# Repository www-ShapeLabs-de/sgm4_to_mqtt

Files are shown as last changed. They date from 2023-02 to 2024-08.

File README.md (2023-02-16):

# ESP8266 electricity meter reading head for SGM-C4 meter with homeassistant mqtt-discovery
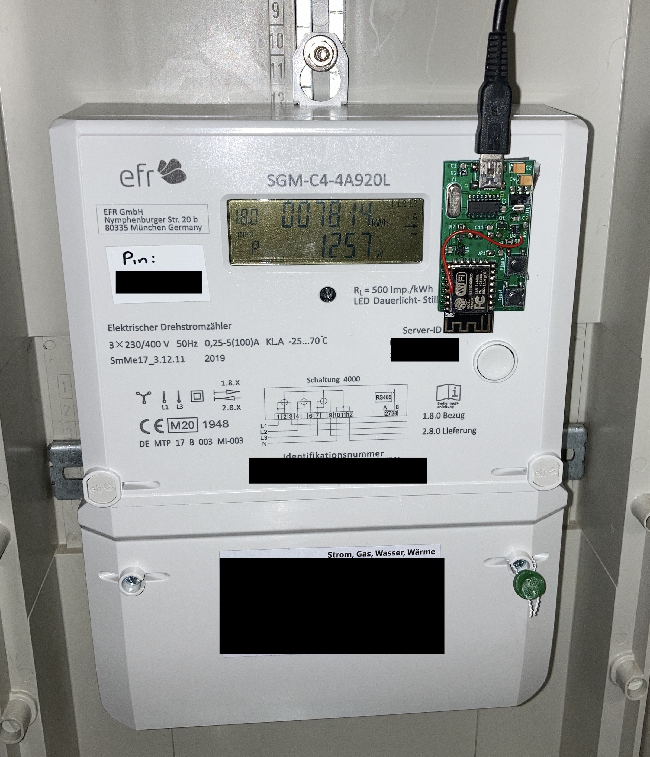
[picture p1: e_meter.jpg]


## Introduction
This project represents a complete electricity meter reading head for the SGM-C4 meter based on ESP8266. No other hardware like a Raspberry-Pi or similar is needed except for the hardware mentioned here. This read head is specially developed for homeassistant, but can also be used for other home automation systems via manual MQTT configuration.
The SML data set is read from the SGM-C4 meter via the optical interface and decoded. The data is transferred to homeassistant via MQTT. At startup, the read head automatically sets itself up as a device via mqtt-discovery with all its entities.

## Hardware
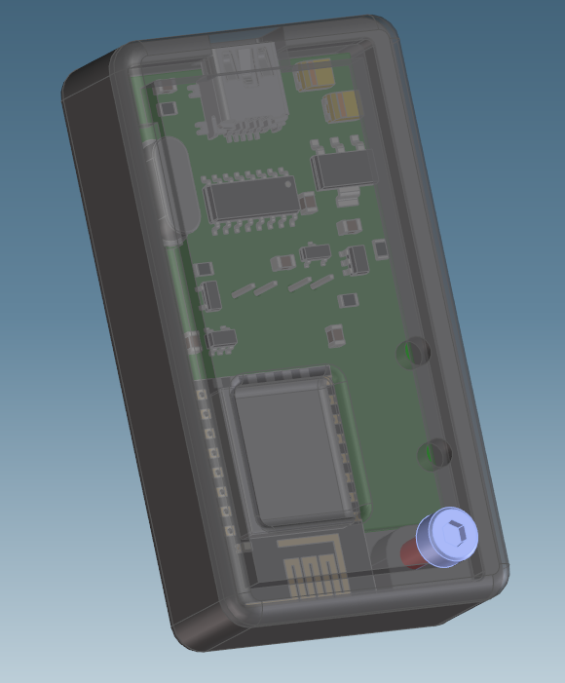
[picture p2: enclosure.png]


### Electronics
All components are easy to obtain, the optical TX side (U5, Q2, D1, R7, C10) can also remain unpopulated. Currently it is not used. When choosing the IR receiving diode (Q3) the SFH309 should be used. With other diodes there could be problems. Otherwise the circuit is quite trivial and should be easy to build and populate. Board data are available as KiCad files in the repo. For standard-use it's necessary to set Jumper JP2 to 1-2

### Housing
CAD data for a housing is available as a STEP file. There are also STL files that can be printed directly. If no printer is available, the circuit board can also be attached to the electricity meter with double-sided adhesive tape and a few plastic plates (approx. 3 mm thick) as a spacer block.

## Software / Config
For this project it is necessary to enable the complete data output of the electricity meter by means of a PIN code. You can get the PIN code from your metering point operator (in german: "Messstellenbetreiber"), a phone call is sufficient. The metering point operator is obliged to provide the PIN code. For this purpose, you should have the customer data and the meter number available.

### Entering the PIN code
To enter the PIN, you must first press the mechanical key once. After that, the PIN display appears in the lower display line and the first digit appears with a
"0". To enter your PIN, press the key repeatedly until the value of the first digit of your personal PIN appears in the display. After a short waiting time the device is ready (display of a "0") for the input of the 2nd digit of your PIN. Enter the corresponding value of your personal PIN here as well. Then repeat the entry procedure for the 3rd and 4th digits of your PIN in the same way. 

### Configuration of the software
The WLAN access data must be entered in the #define area of the software. In addition, the address or IP of the MQTT broker and its access data are required.
Under "Location" and "Name" the device name as well as its installation location can be assigned. This also results in the MQTT topic. 

```
#define SOFTWARE_VERSION      "v1.4"
#define WLAN_SSID             "myssid"
#define WLAN_PASS             "mywifipasswd"
#define MQTT_SERVER           "192.168.1.2"
#define MQTT_SERVERPORT       1883 					// use 8883 for SSL
#define MQTT_USERNAME         "mqttuser"
#define MQTT_KEY              "mosquitto"
#define LOCATION              "my_location"
#define NAME                  "E_Meter"
//#define OTA_PASS            "admin"
#define STATE_UPDATE_INTERVAL 5000 					// MQTT state update interval in [ms] (<5000ms could be critical for parsing in worst case)
#define AVAILABILITY_ONLINE   "online"
#define AVAILABILITY_OFFLINE  "offline"
```

Afterwards the software can be flashed to the ESP8266 with a mini-USB cable and the Arduino IDE. To enter the flash mode, the flash button must be held down while pressing the reset button. After the flash process, the ESP should be reset again.

After that the device should be found automatically in HASSIO with all its entities:

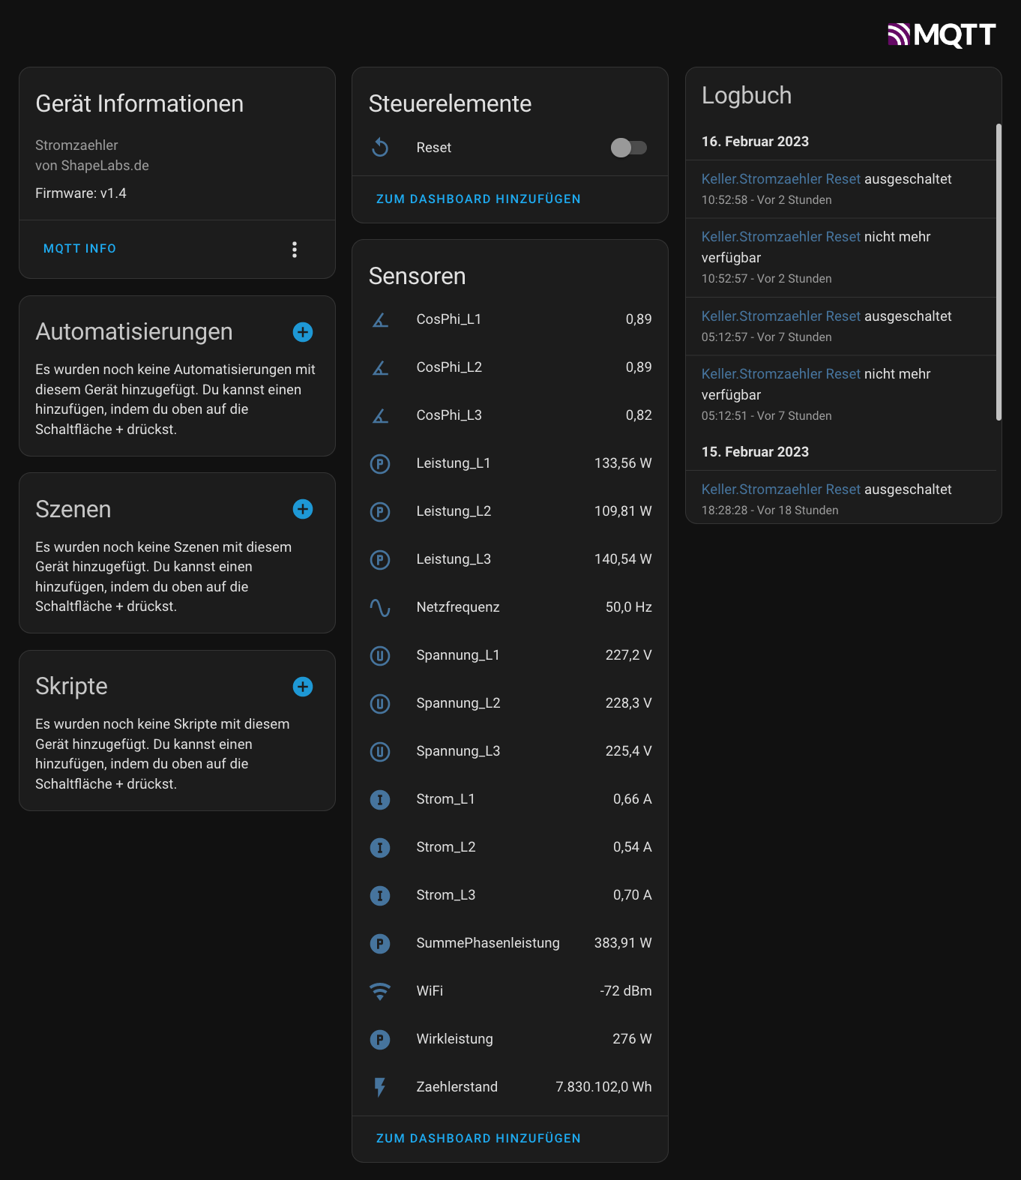
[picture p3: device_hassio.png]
The Device with its entities in HASSIO


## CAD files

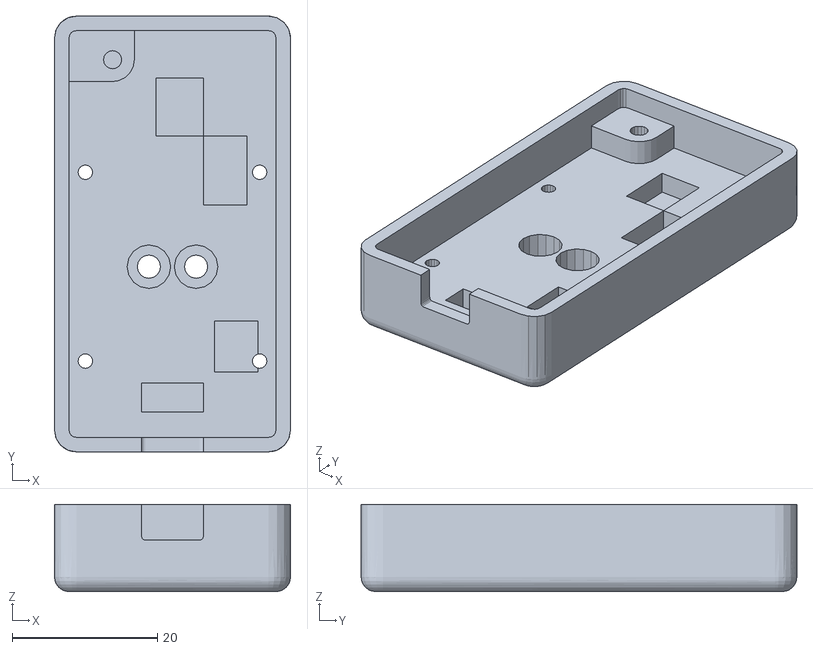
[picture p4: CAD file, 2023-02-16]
Enclosure/electricity_meter_reading_head_enclosure_bottom.stl
32.5 x 60.0 x 12.0

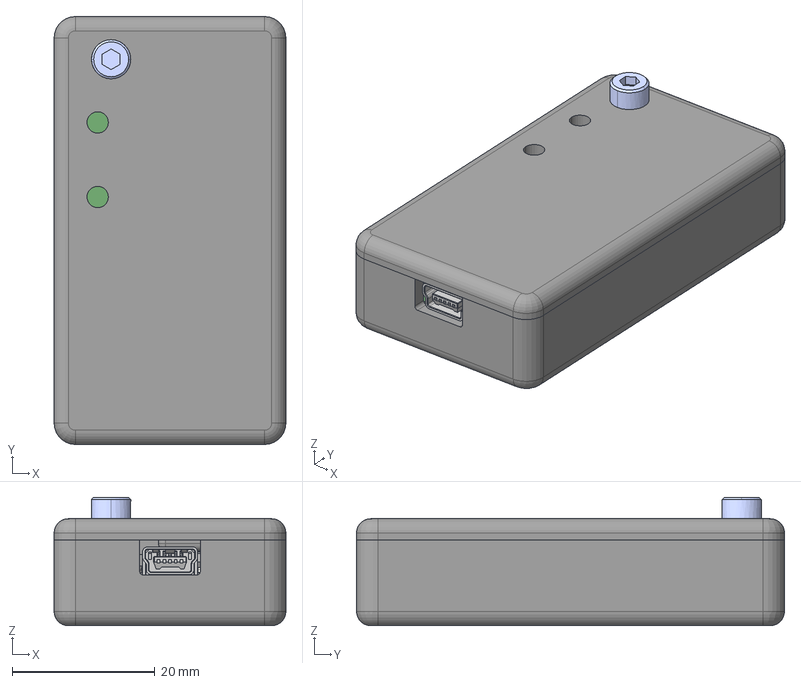
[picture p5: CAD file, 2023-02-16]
Enclosure/electricity_meter_reading_head_enclosure.stp
32.5 x 60.0 x 18.0 mm
Srew_M3x10_DIN912
USB_Mini_B_SMD_buchse
T48
T47
T46
T45
T44
T43
T42
T41
T40
T39
T38
T37
T36
T35
T34
T33
T32
T31
T30
T29
T28
T27
T26
T25
T24
T23
T22
T21
T20
T19
T18
T17
T16
T15
T14
T13
T12
T11
T10
T9
T8
T7
T6
T5
T4
T3
T2
T1
B1
Print_Enclosure_Top
Print_Enclosure_Bottom

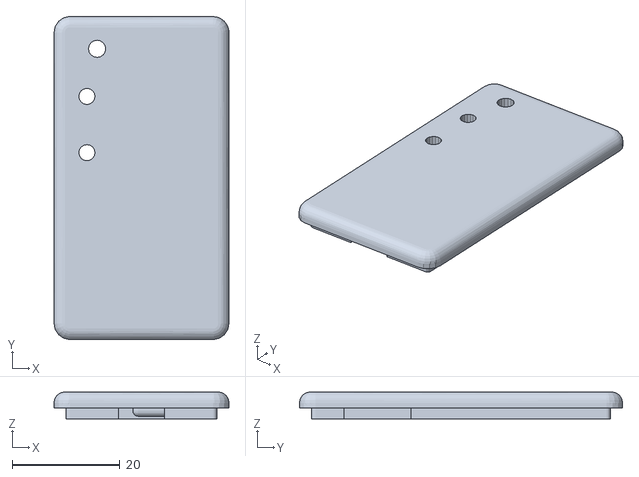
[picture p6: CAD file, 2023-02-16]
Enclosure/electricity_meter_reading_head_enclosure_top.stl
32.5 x 60.0 x 5.00

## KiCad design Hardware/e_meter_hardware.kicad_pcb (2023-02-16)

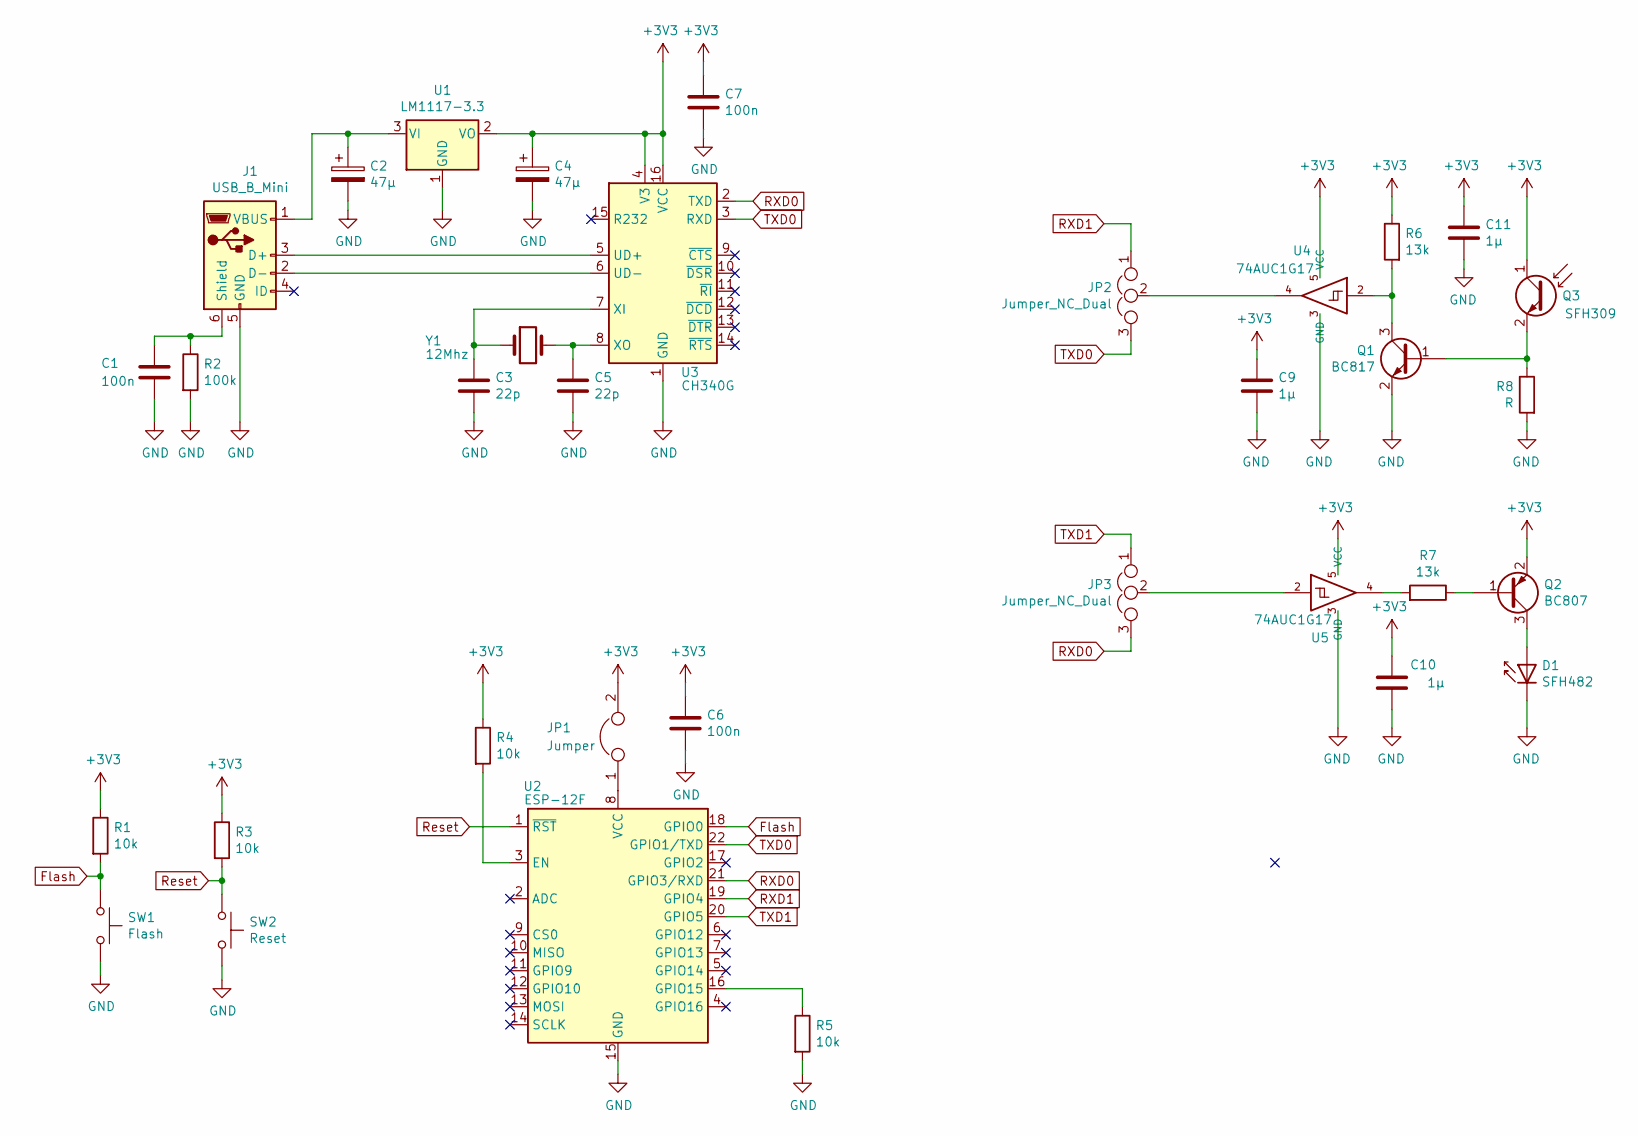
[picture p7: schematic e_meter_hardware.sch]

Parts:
C1, C6, C7: 100n; C_0805_2012Metric
C2, C4: 47µ; CP_EIA-3528-21_Kemet-B
C3, C5: 22p; C_0805_2012Metric
C9, C10, C11: 1µ; C_0805_2012Metric
D1: SFH482; LED_D3.0mm_Clear
J1: USB_B_Mini; USB_Mini-B_Wuerth_65100516121_Horizontal
JP1: Jumper; SolderJumper-2_P1.3mm_Open_RoundedPad1.0x1.5mm
JP2, JP3: Jumper_NC_Dual; SolderJumper-3_P1.3mm_Open_RoundedPad1.0x1.5mm
Q1: BC817; SOT-23
Q2: BC807; SOT-23
Q3: SFH309; LED_D3.0mm_Clear
R1, R3, R4, R5: 10k; R_0805_2012Metric
R2: 100k; R_0805_2012Metric
R6, R7: 13k; R_0805_2012Metric
R8: R; R_0805_2012Metric
SW1: Flash; SW_Push_1P1T_NO_6x6mm_H9.5mm
SW2: Reset; SW_Push_1P1T_NO_6x6mm_H9.5mm
U1: LM1117-3.3; SOT-223-3_TabPin2
U2: ESP-12F; ESP-12E
U3: CH340G; SOIC-16_3.9x9.9mm_P1.27mm
U4, U5: 74AUC1G17; SOT-23-5
Y1: 12Mhz; Crystal_HC49-U_Vertical

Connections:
+3V3: C4.1, C6.1, C7.1, C9.1, C10.1, C11.1, JP1.2, Q2.2 (E), Q3.1 (C), R1.1, R3.1, R4.1, R6.1, U1.2 (VO), U3.4 (V3), U3.16 (VCC), U4.5 (VCC), U5.5 (VCC)
Flash: R1.2, SW1.1, U2.18 (GPIO0)
GND: C1.2, C2.2, C3.2, C4.2, C5.2, C6.2, C7.2, C9.2, C10.2, C11.2, D1.1 (K), J1.5 (GND), Q1.2 (E), R2.2, R5.2, R8.2, SW1.2, SW2.2, U1.1 (GND), U2.15 (GND), U3.1 (GND), U4.3 (GND), U5.3 (GND)
unnamed: C1.1, J1.6 (Shield), R2.1
unnamed: C2.1, J1.1 (VBUS), U1.3 (VI)
unnamed: C3.1, U3.7 (XI), Y1.1
unnamed: C5.1, U3.8 (XO), Y1.2
unnamed: D1.2 (A), Q2.3 (C)
unnamed: J1.2 (D-), U3.6 (UD-)
unnamed: J1.3 (D+), U3.5 (UD+)
unnamed: JP1.1, U2.8 (VCC)
unnamed: JP2.2, U4.4
unnamed: JP3.2, U5.2
unnamed: Q1.1 (B), Q3.2 (E), R8.1
unnamed: Q1.3 (C), R6.2, U4.2
unnamed: Q2.1 (B), R7.1
unnamed: R4.2, U2.3 (EN)
unnamed: R5.1, U2.16 (GPIO15)
unnamed: R7.2, U5.4
RXD0: JP3.3, U2.21 (GPIO3/RXD), U3.2 (TXD)
RXD1: JP2.1, U2.19 (GPIO4)
Reset: R3.2, SW2.1, U2.1 (~RST)
TXD0: JP2.3, U2.22 (GPIO1/TXD), U3.3 (RXD)
TXD1: JP3.1, U2.20 (GPIO5)

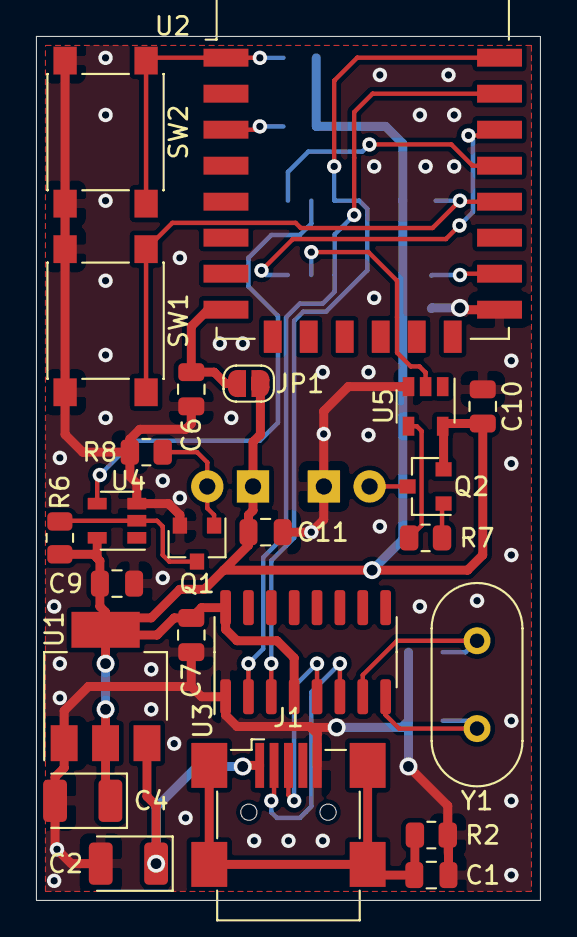
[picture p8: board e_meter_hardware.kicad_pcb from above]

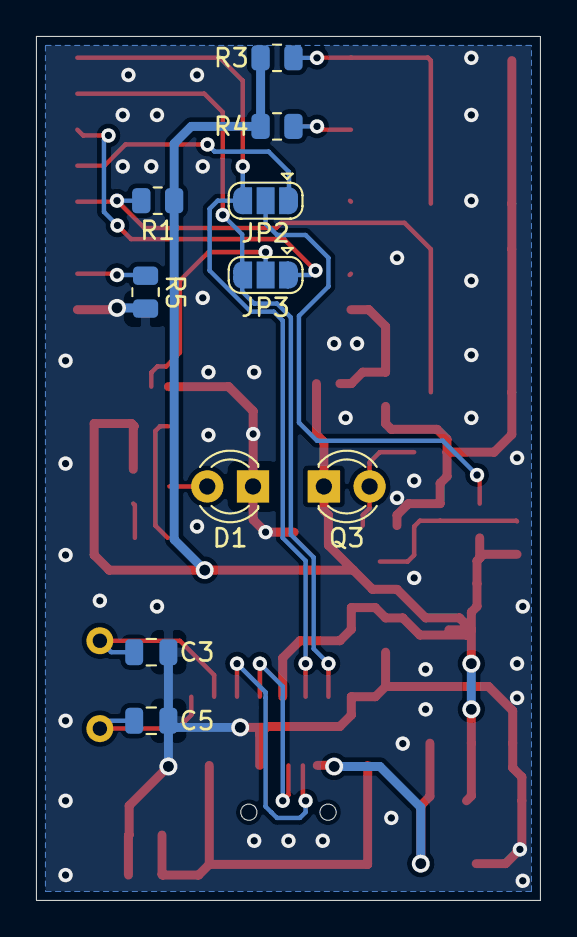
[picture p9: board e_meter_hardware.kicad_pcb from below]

Board: 2 copper layers, 28.0 x 48.0 mm, 34 parts (10 on the bottom side), 24 nets.

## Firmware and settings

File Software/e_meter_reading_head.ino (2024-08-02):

/*------------------------------------------------------------------------------
 Copyright:	  Henning Schaper  mailto: henningschaper@gmx.de
 Author:		 Henning Schaper
 Remarks:		none
 known Problems: none
 Version:		v1.4	01.04.2022
 Description:  	 Hassio 
 				 Processor: ESP8266 (ESP12F)
 				 Features:  - homeassistant autoconfig
 				 			- OTA
 				 			- JSON over MQTT 
 				 			- 
 				 			- 
 				 			- static wifi, no wifimanager (more stable)

------------------------------------------------------------------------------*/

//----------------------------------------------------------------------------//
//-------------------------------- Includes  ---------------------------------//
//----------------------------------------------------------------------------//
#include <ESP8266WiFi.h>
#include <ArduinoJson.h>
#include <PubSubClient.h>
#include <ArduinoOTA.h>
#include <SoftwareSerial.h>

//----------------------------------------------------------------------------//
//-------------------------------- Config  -----------------------------------//
//----------------------------------------------------------------------------//
#define SOFTWARE_VERSION		"v1.6"
#define WLAN_SSID 				"myssid"
#define WLAN_PASS 				"mypass"
#define MQTT_SERVER 			"192.168.2.5"
#define MQTT_SERVERPORT 		1883 					// use 8883 for SSL
#define MQTT_USERNAME 			"mqttuser"
#define MQTT_KEY 				"mosquitto"
#define LOCATION				"Keller"
#define NAME 					"Stromzaehler"
//#define OTA_PASS				"admin"
#define STATE_UPDATE_INTERVAL	5000 					// MQTT state update interval in [ms] (<5000ms could be critical for parsing in worst case)
#define AVAILABILITY_ONLINE 	"online"
#define AVAILABILITY_OFFLINE 	"offline"
#define DEBUG
//#define DEBUG2

//----------------------------------------------------------------------------//
//--------------------------------- Macros -----------------------------------//
//----------------------------------------------------------------------------//
#define SOFT_RX_PIN		4
#define SOFT_TX_PIN		5
#define SML_MESSAGE_SIZE 600

//----------------------------------------------------------------------------//
//----------------------------- Constants & LUTs -----------------------------//
//----------------------------------------------------------------------------//
const uint8_t startSequence[] = 						{ 0x1B, 0x1B, 0x1B, 0x1B, 0x01, 0x01, 0x01, 0x01 }; //start sequence of SML protocol
const uint8_t stopSequence[]  = 						{ 0x1B, 0x1B, 0x1B, 0x1B, 0x1A }; //end sequence of SML protocol

const uint8_t Zaehlerstand_Bezug_sequence[] = 			{0x77, 0x07, 0x01, 0x00, 0x01, 0x08, 0x00, 0xFF}; 
const uint8_t Zaehlerstand_Einspeisung_sequence[] = 	{0x77, 0x07, 0x01, 0x00, 0x02, 0x08, 0x00, 0xFF}; 
const uint8_t Wirkleistung_sequence[] = 				{0x77, 0x07, 0x01, 0x00, 0x10, 0x07, 0x00, 0xFF}; 
const uint8_t Spannung_L1_sequence[] = 					{0x77, 0x07, 0x01, 0x00, 0x20, 0x07, 0x00, 0xFF}; 
const uint8_t Spannung_L2_sequence[] = 					{0x77, 0x07, 0x01, 0x00, 0x34, 0x07, 0x00, 0xFF}; 
const uint8_t Spannung_L3_sequence[] = 					{0x77, 0x07, 0x01, 0x00, 0x48, 0x07, 0x00, 0xFF}; 
const uint8_t Strom_L1_sequence[] = 					{0x77, 0x07, 0x01, 0x00, 0x1F, 0x07, 0x00, 0xFF}; 
const uint8_t Strom_L2_sequence[] = 					{0x77, 0x07, 0x01, 0x00, 0x33, 0x07, 0x00, 0xFF}; 
const uint8_t Strom_L3_sequence[] = 					{0x77, 0x07, 0x01, 0x00, 0x47, 0x07, 0x00, 0xFF}; 
//const uint8_t Phasenwinkel_U-L2_U-L1_sequence[] = 		{0x77, 0x07, 0x01, 0x00, 0x51, 0x07, 0x01, 0xFF}; 
//const uint8_t Phasenwinkel_U-L3_U-L1_sequence[] = 		{0x77, 0x07, 0x01, 0x00, 0x51, 0x07, 0x02, 0xFF}; 
const uint8_t Phi_L1_sequence[] = 						{0x77, 0x07, 0x01, 0x00, 0x51, 0x07, 0x04, 0xFF}; 
const uint8_t Phi_L2_sequence[] = 						{0x77, 0x07, 0x01, 0x00, 0x51, 0x07, 0x0F, 0xFF}; 
const uint8_t Phi_L3_sequence[] = 						{0x77, 0x07, 0x01, 0x00, 0x51, 0x07, 0x1A, 0xFF}; 
const uint8_t Frequenz_sequence[] = 					{0x77, 0x07, 0x01, 0x00, 0x0E, 0x07, 0x00, 0xFF}; 

const float cos_table [] = 	{	1.000000, 0.999847, 0.999389, 0.998626, 0.997557, 0.996184, 0.994507, 0.992526, 0.990241, 0.987655,
 								0.984766, 0.981577, 0.978088, 0.974300, 0.970215, 0.965833, 0.961156, 0.956186, 0.950923, 0.945370, 
 								0.939529, 0.933400, 0.926987, 0.920290, 0.913312, 0.906055, 0.898521, 0.890713, 0.882633, 0.874283, 
 								0.865666, 0.856785, 0.847642, 0.838240, 0.828582, 0.818671, 0.808510, 0.798102, 0.787451, 0.776558, 
 								0.765429, 0.754066, 0.742472, 0.730652, 0.718608, 0.706345, 0.693866, 0.681175, 0.668277, 0.655174, 
 								0.641871, 0.628371, 0.614680, 0.600802, 0.586739, 0.572498, 0.558081, 0.543495, 0.528742, 0.513827, 
 								0.498756, 0.483532, 0.468161, 0.452647, 0.436994, 0.421208, 0.405293, 0.389255, 0.373097, 0.356826, 
 								0.340446, 0.323961, 0.307378, 0.290701, 0.273935, 0.257085, 0.240157, 0.223155, 0.206086, 0.188953, 
 								0.171763, 0.154520, 0.137230, 0.119898, 0.102529, 0.085129, 0.067703, 0.050257, 0.032795, 0.015323, 0.000000};

//----------------------------------------------------------------------------//
//------------------------------- Variables  ---------------------------------//
//----------------------------------------------------------------------------//
uint8_t smlMessage[SML_MESSAGE_SIZE];
uint16_t parse_index = 0;
uint16_t smlIndex = 0;
uint8_t inByte = 0;
uint8_t startIndex = 0;
uint8_t stopIndex = 0;
uint8_t sml_read_state = 0;

double Zaehlerstand_180 = 0;
double Zaehlerstand_280 = 0;
double Wirkleistung = 0;
double SpannungL1 = 0;
double SpannungL2 = 0;
double SpannungL3 = 0;
double StromL1 = 0;
double StromL2= 0;
double StromL3= 0;
double Phi_L1 = 0;
double Phi_L2 = 0;
double Phi_L3 = 0;
double Netzfrequenz = 0;

char identifier[24];
char MQTT_TOPIC_AVAILABILITY[128];
char MQTT_TOPIC_STATE[128];
char MQTT_TOPIC_COMMAND[128];

uint32_t PreviousStateUpdateTime = 0;
uint32_t CurrentTime = millis();
bool parse_error_flag = false;

//----------------------------------------------------------------------------//
//--------------------------------- Objects ----------------------------------//
//----------------------------------------------------------------------------//
SoftwareSerial SoftSerial(SOFT_RX_PIN, SOFT_TX_PIN);
WiFiClient wifiClient;
PubSubClient mqttClient(wifiClient);

//----------------------------------------------------------------------------//
//------------------------------ Main Program --------------------------------//
//----------------------------------------------------------------------------//
void setup()
{
	Serial.begin(115200);
	Serial.println("Start INIT");
	SoftSerial.begin(9600);
	
	snprintf(identifier, sizeof(identifier), "%s.%s",LOCATION,NAME); 
	snprintf(MQTT_TOPIC_AVAILABILITY, 127, "%s/%s/status", LOCATION, NAME);
	snprintf(MQTT_TOPIC_STATE, 127, "%s/%s/state", LOCATION, NAME);
	snprintf(MQTT_TOPIC_COMMAND, 127, "%s/%s/command", LOCATION, NAME);

	connect_WiFi();
	setupOTA();
	
	mqttClient.setServer(MQTT_SERVER, MQTT_SERVERPORT);
	mqttClient.setKeepAlive(10);
	mqttClient.setBufferSize(2048);
	mqttClient.setCallback(mqttCallback);

	mqttReconnect();
	Serial.println("INIT COMPLETE!");
}

void loop()
{
	mqttClient.loop();
	ArduinoOTA.handle();

	if(!sml_read_state)
		get_sml_sync();
	else if (sml_read_state == 1)
		get_sml_message();
	else if(sml_read_state == 2)
	{
		Zaehlerstand_180 = get_values_from_SML(Zaehlerstand_Bezug_sequence);
		Zaehlerstand_280 = get_values_from_SML(Zaehlerstand_Einspeisung_sequence);
		Wirkleistung = get_values_from_SML(Wirkleistung_sequence);
		SpannungL1 = get_values_from_SML(Spannung_L1_sequence);
		SpannungL2 = get_values_from_SML(Spannung_L2_sequence);
		SpannungL3 = get_values_from_SML(Spannung_L3_sequence);
		StromL1 = get_values_from_SML(Strom_L1_sequence);
		StromL2 = get_values_from_SML(Strom_L2_sequence);
		StromL3 = get_values_from_SML(Strom_L3_sequence);
		Phi_L1 = get_values_from_SML(Phi_L1_sequence);
		Phi_L2 = get_values_from_SML(Phi_L2_sequence);
		Phi_L3 = get_values_from_SML(Phi_L3_sequence);
		Netzfrequenz = get_values_from_SML(Frequenz_sequence);

		if(!parse_error_flag)							//Parsing successfull completed?
			sml_read_state = 3;							//
		else											//else: Error@Parsing! Discard any data, to prevent publishing zero-values ore other wrong values
			sml_read_state = 0;							//go to next state of statemachine -> STATE 3: publishing data
	}
	
	if(STATE_UPDATE_INTERVAL <= (CurrentTime - PreviousStateUpdateTime))
	{
		if (WiFi.status() != WL_CONNECTED) 
			connect_WiFi(); 

		if (!mqttClient.connected())
			mqttReconnect();
		
		if(sml_read_state == 3)
		{
			#ifdef DEBUG
				Serial.println("Publish");
			#endif
			publishState();
			sml_read_state = 0;
		}
	}
	CurrentTime = millis();							// Get current time
}

//----------------------------------------------------------------------------//
//----------------------- Standard Functions for ESP -------------------------//
//----------------------------------------------------------------------------//
void Reset_ESP()
{
	WiFi.disconnect(true);
	delay(1000);
	ESP.restart();	
}

void connect_WiFi()
{
	Serial.print("Connecting to ");
	Serial.println(WLAN_SSID);
	
	WiFi.mode(WIFI_STA);
	WiFi.begin(WLAN_SSID, WLAN_PASS);

	while (WiFi.status() != WL_CONNECTED)
	{
		delay(100);
		Serial.print(".");
	}

	Serial.println("");
	Serial.println("WiFi connected");
	Serial.println("IP address: ");
	Serial.println(WiFi.localIP());
}

void setupOTA()
{
	ArduinoOTA.onStart([]() { Serial.println("Start"); });
	ArduinoOTA.onEnd([]() { Serial.println("\nEnd"); });

	ArduinoOTA.onProgress([](unsigned int progress, unsigned int total)
	{
		Serial.printf("Progress: %u%%\r\n", (progress / (total / 100)));
	});

	ArduinoOTA.onError([](ota_error_t error)
	{
		Serial.printf("Error[%u]: ", error);
		if (error == OTA_AUTH_ERROR) Serial.println("Auth Failed");
		else if (error == OTA_BEGIN_ERROR) Serial.println("Begin Failed");
		else if (error == OTA_CONNECT_ERROR) Serial.println("Connect Failed");
		else if (error == OTA_RECEIVE_ERROR) Serial.println("Receive Failed");
		else if (error == OTA_END_ERROR) Serial.println("End Failed");
	});

	ArduinoOTA.setHostname(identifier);
	#ifdef OTA_PASS
		ArduinoOTA.setPassword(OTA_PASS);
	#endif
	ArduinoOTA.begin();
}


void mqttReconnect()
{
	for(int attempt = 0; attempt < 3; ++attempt) 
	{
		Serial.print("Connecting MQTT....");
		if(mqttClient.connect(identifier, MQTT_USERNAME, MQTT_KEY, AVAILABILITY_ONLINE, 1, true, AVAILABILITY_OFFLINE)) 
		{	
			Serial.println("Connected!");
			mqttClient.publish(MQTT_TOPIC_AVAILABILITY, AVAILABILITY_ONLINE, true);
			
			Serial.println("Sending Autoconfig....");

			publish_autoconfig_entity("WiFi","dBm","mdi:wifi",3);
			publish_autoconfig_entity("Zaehlerstand_180","Wh","mdi:flash",1);
			publish_autoconfig_entity("Zaehlerstand_280","Wh","mdi:flash",1);
			publish_autoconfig_entity("Wirkleistung","W","mdi:alpha-p-circle",3);
			publish_autoconfig_entity("SummePhasenleistung","W","mdi:alpha-p-circle",3);
			publish_autoconfig_entity("Spannung_L1","V","mdi:alpha-u-circle-outline",3);
			publish_autoconfig_entity("Spannung_L2","V","mdi:alpha-u-circle-outline",3);
			publish_autoconfig_entity("Spannung_L3","V","mdi:alpha-u-circle-outline",3);
			publish_autoconfig_entity("Strom_L1","A","mdi:alpha-i-circle",3);
			publish_autoconfig_entity("Strom_L2","A","mdi:alpha-i-circle",3);
			publish_autoconfig_entity("Strom_L3","A","mdi:alpha-i-circle",3);
			publish_autoconfig_entity("cosPhi_L1"," ","mdi:angle-acute",3);
			publish_autoconfig_entity("cosPhi_L2"," ","mdi:angle-acute",3);
			publish_autoconfig_entity("cosPhi_L3"," ","mdi:angle-acute",3);
			publish_autoconfig_entity("Leistung_L1","W","mdi:alpha-p-circle-outline",3);
			publish_autoconfig_entity("Leistung_L2","W","mdi:alpha-p-circle-outline",3);
			publish_autoconfig_entity("Leistung_L3","W","mdi:alpha-p-circle-outline",3);
			publish_autoconfig_entity("Netzfrequenz","Hz","mdi:sine-wave",3);
			publish_autoconfig_entity("Reset"," ","mdi:replay" ,2);

			Serial.println("Subscribing Topics....");
			mqttClient.subscribe(MQTT_TOPIC_COMMAND);
			Serial.println("Success!");
			break;
		}
		else
		{
			delay(5000);
			Serial.print("FAILED, Retry...");
		}
	}
}

//----------------------------------------------------------------------------//
//----------------------------- MQTT Functions -------------------------------//
//----------------------------------------------------------------------------//
void mqttCallback(char* topic, byte* payload, unsigned int length)
{
	if (strcmp(topic, MQTT_TOPIC_COMMAND) == 0)
	{
		DynamicJsonDocument commandJson(256);
		char payloadText[length + 1];
		snprintf(payloadText, length + 1, "%s", payload);
		DeserializationError err = deserializeJson(commandJson, payloadText);

		if (!err)
		{
			String reset = commandJson["Reset"].as<String>();
			if (reset == "on")
				Reset_ESP();									//ECHO
		}
	}
}

void publishState()
{
	DynamicJsonDocument stateJson(512);
	char payload[512];
	
	float P_L1 = my_cos_phi(Phi_L1)*SpannungL1*StromL1;
	float P_L2 = my_cos_phi(Phi_L1)*SpannungL2*StromL2;
	float P_L3 = my_cos_phi(Phi_L1)*SpannungL3*StromL3;

	stateJson["Reset"] = "off";
	stateJson["WiFi"] = WiFi.RSSI();
	stateJson["Zaehlerstand_180"] = String(Zaehlerstand_180,1);
	stateJson["Zaehlerstand_280"] = String(Zaehlerstand_280,1);
	stateJson["Wirkleistung"] = String(Wirkleistung,0);
	stateJson["Spannung_L1"] = String(SpannungL1,1);
	stateJson["Spannung_L2"] = String(SpannungL2,1);
	stateJson["Spannung_L3"] = String(SpannungL3,1);
	stateJson["Strom_L1"] = String(StromL1,2);
	stateJson["Strom_L2"] = String(StromL2,2);
	stateJson["Strom_L3"] = String(StromL3,2);
	stateJson["cosPhi_L1"] = String(my_cos_phi(Phi_L1),2);
	stateJson["cosPhi_L2"] = String(my_cos_phi(Phi_L2),2);
	stateJson["cosPhi_L3"] = String(my_cos_phi(Phi_L3),2);
	stateJson["Leistung_L1"] = String(P_L1,2);
	stateJson["Leistung_L2"] = String(P_L2,2);
	stateJson["Leistung_L3"] = String(P_L3,2);
	stateJson["SummePhasenleistung"] = String(P_L1+P_L2+P_L3);
	stateJson["Netzfrequenz"] = String(Netzfrequenz,1);

	serializeJson(stateJson, payload);
	mqttClient.publish(MQTT_TOPIC_STATE, payload, true);

	PreviousStateUpdateTime = millis();
}

//TYPE: 1=Energy-Meter, 2=Switch, 3=Sensor
void publish_autoconfig_entity(const char value_name[], const char unit[], const char icon[], uint8_t type)
{
	char mqttPayload[1024];
	DynamicJsonDocument autoconfPayload(1024);
	DynamicJsonDocument device(256);
	char MQTT_TOPIC_AUTOCONF_TOPIC[128];

	device["identifiers"] = String("[") + identifier + String("]");
	device["manufacturer"] = "ShapeLabs.de";
	device["model"] = NAME;
	device["name"] = identifier;
	device["sw_version"] = SOFTWARE_VERSION;
	autoconfPayload["device"] = device.as<JsonObject>();
	autoconfPayload["availability_topic"] = MQTT_TOPIC_AVAILABILITY;
	autoconfPayload["state_topic"] = MQTT_TOPIC_STATE;
	autoconfPayload["name"] = identifier + String(" ") + value_name;
	autoconfPayload["unique_id"] = identifier + String("_") + value_name;
	autoconfPayload["icon"] = icon;
	autoconfPayload["value_template"] = String("{{value_json.") + value_name + String("}}");
	
	if(type==1)
	{
		autoconfPayload["device_class"] = "energy";
		autoconfPayload["state_class"] = "total_increasing";
		type = 3;
	}
	else if(type==2)
	{
		autoconfPayload["command_topic"] = MQTT_TOPIC_COMMAND;
		autoconfPayload["payload_on"] = String("{\"") + value_name + String("\": \"on\"}");
		autoconfPayload["payload_off"] = String("{\"") + value_name + String("\": \"off\"}");
		autoconfPayload["state_on"] = "on";
		autoconfPayload["state_off"] = "off";
		snprintf(MQTT_TOPIC_AUTOCONF_TOPIC, 127, "homeassistant/switch/%s/%s_%s/config", LOCATION, NAME, value_name);
	}
	if(type == 3)
	{
		autoconfPayload["unit_of_measurement"] = unit;
		snprintf(MQTT_TOPIC_AUTOCONF_TOPIC, 127, "homeassistant/sensor/%s/%s_%s/config", LOCATION, NAME, value_name);
	}

	serializeJson(autoconfPayload, mqttPayload);
	mqttClient.publish(MQTT_TOPIC_AUTOCONF_TOPIC, mqttPayload, true);
	device.clear();
	autoconfPayload.clear();
	delay(100);
}

//----------------------------------------------------------------------------//
//----------------------------- SML Functions --------------------------------//
//----------------------------------------------------------------------------//
void get_sml_sync()																//STATE 0: Function to finde the start sequence of an incomming sml-packet
{
	clear_all_sml();															//clear RX-Buffer, clear message buffer from any old data fragments, reset all flags and counter
	delay(20);																	//wait until there's any fresh data in the RX-buffer again

	while(SoftSerial.available())												//start to read the RX-buffer while there is any data
	{
		inByte = SoftSerial.read(); 											//reading data
		
		if(inByte == startSequence[startIndex]) 								//in case incomming byte matches the start sequence at position 0,1,2...
		{
			smlMessage[startIndex++] = inByte; 									//set smlMessage element at position 0,1,2 to inByte value
			if(startIndex == sizeof(startSequence)) 							//all start sequence values have been identified
			{
				smlIndex = startIndex;
				#ifdef DEBUG 
					Serial.println("SML start found");							//some debug output...
				#endif
				sml_read_state = 1;												//go to next state of statemachine -> STATE 1: recording
				//startIndex = 0;
				break;															//leaving the loop
			}
		}
		else
			startIndex = 0;														//Jump back, next try to hit the start sequence
	}
}

void get_sml_message()															//STATE 1: Function to record the complete sml-packet till it's end by checking continously for end-secuence
{
	while(SoftSerial.available())												//start to read the RX-buffer while there is any data
	{
		inByte = SoftSerial.read();												//reading data
		smlMessage[smlIndex++] = inByte;										//writing data to message buffer

		#ifdef DEBUG2															//debug output on hw-serial of incomming data
			if(!(inByte & 0xF0))												//print leading zero if nessecary
				Serial.print("0");
			Serial.print(inByte, HEX);											//print value as hex
			Serial.print(" ");							
			if(!(smlIndex%30))													//newline after 30 values
				Serial.print("\r\n");
		#endif

		if(inByte == stopSequence[stopIndex])									//in case incomming byte matches the start sequence at position 0,1,2...
		{
			stopIndex++;														// hit, try next digit in next pass of loop
			if(stopIndex == sizeof(stopSequence))								// complete stop sequence found
			{
				#ifdef DEBUG 							
					Serial.print("\r\n");
					Serial.println("SML-message valid recording complete");
				#endif

				sml_read_state = 2;												//go to next state of statemachine -> STATE 2: parsing of all the data
				break;															// leaving the loop
			}
		}
		else
			stopIndex = 0;

		if(smlIndex > sizeof(smlMessage))										//no stop sequence found in the complete message buffer, prevending buffer overflow
		{
			#ifdef DEBUG
				Serial.print("\r\n");
				Serial.println("ERROR no valid SML-message found");
			#endif

			sml_read_state = 0;													// canceling, next try, -> STATE 0: clearing buffers & flags, searching start sequence in incomming data
			break;																// leaving the loop
		}
	}
}


double get_values_from_SML(const uint8_t* sequence) 
{
	uint32_t temp = 0;
	uint8_t sequence_index = 0; 												//start at position 0 of recorded sml-message
	float scaler = 0.0;
	double output = 0;
	uint8_t n_bytes = 0;
	bool matched = false;


	for(uint16_t x = parse_index; x<sizeof(smlMessage); x++)					//for as long there are not reached the end of message buffer
	{ 
		if(smlMessage[x] == sequence[sequence_index]) 							//compare with sequence
		{ 
			sequence_index++;
			if(sequence_index == 8)												//MATCH!!complete sequence is found
			{
				parse_index = x+1;
				matched = true;
				#ifdef DEBUG
					Serial.println("Sequence matched at: " + String(parse_index));
				#endif
				break;
			}
		}
	}

	if(matched)
	{
		while(parse_index < sizeof(smlMessage))
		{
			if((smlMessage[parse_index] & 0xF0) == 0x50)						//Scaler found first int-value of data is the scaler)
			{
				scaler = pow(10.0,(int8_t)smlMessage[parse_index+1]);
				#ifdef DEBUG
					Serial.println("Scaler found:" + String(smlMessage[parse_index+1]));
				#endif
				parse_index += smlMessage[parse_index] & 0x0F;					//Go to the value (the scaler data is followed by the value data)
				break;
			}
			else if ((smlMessage[parse_index] & 0xF0) == 0x70)					//List index found
				parse_index++;													//Jump into List
			else
				parse_index += smlMessage[parse_index] & 0x0F;					//Jump to next List item
		}
		
		n_bytes= (smlMessage[parse_index]&0x0F)-1;
		
		#ifdef DEBUG
			Serial.println("Value with: " + String(n_bytes) + "byte is parsing now");
		#endif

		for(uint8_t i = 0; i < n_bytes; i++)			//parse all bytes of value to temp
		{
			parse_index++;
			#ifdef DEBUG
				Serial.println("Index:" + String(parse_index));
				Serial.println("Value:" + String(smlMessage[parse_index]));
			#endif
			temp += smlMessage[parse_index];
			if(!(n_bytes-i <= 1))
				temp <<= 8;
		}
		output= (double)temp*scaler;

		#ifdef DEBUG
			Serial.println("Sequence found " + String(n_bytes) + "Byte parse complete:" + String(output));
		#endif

		return(output);
	}

	else
	{
		#ifdef DEBUG
			Serial.println("Parse ERROR - No Sequence found");
		#endif
		parse_error_flag = true;
		return 0;
	}
}



void clear_all_sml(void)
{
	while(SoftSerial.available())												//empty the RX-buffer
		SoftSerial.read();
	for(uint16_t i = 0; i<sizeof(smlMessage);i++)								//empty message-buffer
		smlMessage[i]=0;
	parse_index = 0;															//reset all indexes and flags
	smlIndex = 0;
	inByte = 0;
	startIndex = 0;
	stopIndex = 0;
	sml_read_state = 0;
	parse_error_flag = false;
}
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
